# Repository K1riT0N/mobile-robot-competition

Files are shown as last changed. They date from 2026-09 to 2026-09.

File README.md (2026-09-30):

# Mobile Robot Competition

This repository documents a robotics competition project focused on designing and building two mobile robots: one autonomous robot and one manual-controlled robot. The project combines mechanical design, electronics, control programming, testing, and competition documentation into a single development workspace.

The goal is to create competitive robots that can perform assigned field tasks, optimize robot design for reliability, and validate control strategies through repeated testing and iteration.

## Project Overview

The project covers the full engineering cycle for a mobile robot system:

- Mechanical design and CAD modeling
- 3D-printed parts and custom structural components
- Robot assembly and integration
- Sensor, motor, and actuator testing
- Embedded control development and robot programming
- Competition preparation and reporting

The work is divided between:

- Autonomous robot development for self-controlled operation
- Manual robot development for driver-controlled competition tasks
- Testing and tuning for motion, sensing, and field performance

## Repository Structure

- `3D_Printing_Parts_CAD_files/` - CAD files for custom 3D-printed robot parts
- `codes/` - Programming files, testing scripts, and robot control experiments
- `Field_materials_CAD_files/` - Competition field elements and objective models
- `Material_Parts_CAD_files/` - Mechanical and electronic component references
- `Reports/` - Competition-related reports and project documentation
- `Robot_design_CAD_files/` - Full robot assembly and design revisions
- `SuperCool video.mp4` - project video documentation

## Code and Testing

The `codes/` folder contains a mix of control programs and experimental testing work, including:

- Manual control code for robot operation
- Sensor testing folders such as gyro and motor calibration
- Servo and DC motor testing programs
- Development files for iterative competition tuning

This folder reflects the practical process of testing hardware and refining software before final deployment.

## Mechanical Design

The project includes a substantial amount of CAD work for both robot structure and competition field components. These files support:

- Robot frame and mechanism development
- Custom grip, launcher, intake, and support systems
- Part iteration and version tracking
- Full assembly visualization before fabrication

The robot design files show a clear progression from concept to final assembly, with multiple revisions and versions stored in the project.

## Competition Focus

This project is intended to prepare robots for a mobile robotics competition where performance is judged through task completion, reliability, and controlled movement. The system design emphasizes:

- Stability and balance
- Efficient movement and turning
- Sensor-informed control and calibration
- Reusable, modular hardware design
- Continuous refinement based on testing results

## Notes

This GitHub repository is created to organize and share the project work, including design files, software experiments, reports, and competition documentation.

It serves as a record of the team's engineering process and can be used as a reference for future robotics development or similar competition projects.

## Recommended Use

To explore the project:

1. Review the CAD files in the robot and field design folders.
2. Open the testing and code folders to understand the control logic and hardware tuning work.
3. Read the reports in `Reports/` for project milestones and technical documentation.
4. Use the assembly designs as a reference for understanding the final robot configuration.

---

This project demonstrates a complete approach to robot development: from concept to prototype, testing, iteration, and competition-ready design.

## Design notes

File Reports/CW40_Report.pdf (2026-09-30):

## FINAL PROJECT REPORT [WEEK 1]

Group Name: JaiJaiSungLui
Group Number: Group 3
Group members: Nathi, Kullatida, Thannapat Calendar Week: CW40
Date: [Oct 6–12, 2025]

Progress Summary

This week, our team received the components for both the Auto and Manual robots. We began by checking the usability of all electronic components due to the fact that many were found to be broken or damaged. After identifying these issues, we replaced the damaged parts with the working ones.

Next, we made a complete list of all metal parts received, because each part must be returned after the competition. Therefore, we started creating CAD files for every metal part we used in this project including some motor and servo used in this Auto robot.

For the robot design process, we prioritized the Auto Robot over the Manual one. We brainstormed design ideas and built initial prototypes, but we encountered limitations related to the rulebook specification, such as limitation of the robot’s size and the number of motors and servos allowed.

By the end of this week, we came up with the design of the drive frame and the cube collecting mechanism (gate mechanism), and created an assembly CAD file for both the drive frame and gate mechanism.

Next Week Plan

- Begin detailed CAD for the full Auto Robot.
- Start testing motor placement and wiring layout.
- Begin early concept design for the Manual Robot.

Problems Encountered

- Several electronic components were unusable and had to be replaced.
- Design constraints due to limited size and motor count.
- Additional components are required for future design, including wheels, sensors, motors and additional screws.

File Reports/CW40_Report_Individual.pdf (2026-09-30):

### FINAL PROJECT – Individual Report [Week 1]

Group Name: JaiJaiSungLui
Group Number: Group 3
Name: Nathi Ritnatikul
Calendar Week: CW40
Date: [Oct 6–12, 2025]

Week 1 Progress:

- Created CAD files for all metal parts to ensure they are listed for future return.
- Designed several versions of the Auto Robot and refined them according to rulebook specifications.
- Finalized the drive frame and cube collection mechanism (gate) design.
- Created an assembly CAD file of the drive frame and the gate mechanism.

Challenges & Solutions:

- Challenge 1:The rulebook specifications on auto robot have a limitation on its size and the number of electronics components that can be used.
- Solution: We separate the whole robot into each mechanism including drive train, gate mechanism, sensors, and other. Then we assign the electronics to each part so that it is not over the specifications limits.
- Challenge 2: To connect the DC motor and Micro servo to the makeblock metal parts, there is a problem on the size of the screw that the M4 screw (Makeblock) does not fit with the electronics components.
- Solution: Measured and identified compatible screw sizes (either M3 or M2) for proper fit.

Next Week Plan:

- Purchase the required components to complete the robot’s mechanisms.
- Complete the detailed CAD assembly and combine all parts into a single file.
- Begin initial concept design for Manual Robot.

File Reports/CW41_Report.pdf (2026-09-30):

## FINAL PROJECT REPORT [WEEK 2]

Group Name: JaiJaiSungLui
Group Number: Group 3
Group members: Nathi, Kullatida, Thannapat Calendar Week: CW41
Date: [Oct 13–19, 2025]

Progress Summary

This week, our team assembled the drive frame and gate mechanism that were designed in the previous week. Some adjustments are required to ensure the assembled structure fits with the size limitations from the rulebook.

We also began wiring the motors to the Arduino UNO and successfully tested the gyro sensor readings. The CAD design for the Auto Robot (Version 1) was completed and is now ready for real assembling.

For the Manual Robot, we started the design process but faced limitations due to the restricted number of available components that need to be shared to the Auto robot. Therefore, we decided to design it with real components for better visualization and ensure component compatibility.

Next Week Plan

- Begin real assembling the Auto Robot Version 1 and make improvements if necessary.
- Continue wiring and testing the sensors and motor for both Auto and Manual Robots.
- Continue designing the Manual Robot design based on real component setup.

Problems Encountered

- Limited robot size required adjustments to the assembly design.
- Restricted components available for the Manual Robot design.

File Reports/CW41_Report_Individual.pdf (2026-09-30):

### FINAL PROJECT – Individual Report [Week 2]

Group Name: JaiJaiSungLui
Group Number: Group 3
Name: Nathi Ritnatikul
Calendar Week: CW41
Date: [Oct 13–19, 2025]

Week 1 Progress:

- Created CAD files for field objects (Ball and Cube), Electronic parts (Servo and DC motor), and other additional parts.
- Created CAD file for parts that required a 3D printer to be printed and start printing.
- Completed the design on V1 Auto Robot.
- Start designing the Manual robot by separating into different parts according to the functions. (Arms, Drive frame, Launcher)

Challenges & Solutions:

- Challenge 1: While designing the Auto Robot, the rulebook specification on size limit causes the design problem when assembling the cube collecting mechanism to the drive frame.
- Solution: I have made an objective cube in CAD file to compare to the size of the robot and find the most optimal position for the gate mechanism to be placed on.
- Challenge 2: With shared metal parts between the Auto and Manual robots, there is a limit in the number and type of component that can be used which also affects the designing process of the Manual robot.
- Solution: Instead of designing on CAD, we try to assemble with real components left from the Auto robot which visualize how many parts left we got for the Manual robot.

Next Week Plan:

- Finished the Auto robot design and assembled it with real components.
- Test the sensors and motors of the Auto robot.
- Complete the Manual robot design and print the required part for the assembly process.

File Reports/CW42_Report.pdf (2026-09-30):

## FINAL PROJECT REPORT [WEEK 3]

Group Name: JaiJaiSungLui
Group Number: Group 3
Group members: Nathi, Kullatida, Thannapat Calendar Week: CW42
Date: [Oct 20–26, 2025]

Progress Summary

This week, our team is focusing on researching and learning coding strategies for the Auto Robot mission. We studied how to effectively use each electronic component according to its purpose and the mission.

The Auto Robot V1 was finalized and assembled, excluding the wiring process, which we are waiting for adjustment. Moreover, we started 3D printing specific parts required for Auto Robot assembly.

In addition, the Manual Robot design is completed only for the drivetrain and hand mechanism (V1).

Next Week Plan

- Begin wiring and electronic component placement for the Auto Robot,
- Continue testing and coding for the Auto Robot mission.
- Develop and improve the Manual Robot shooting mechanism.

Problems Encountered

- Wiring and electronic component process required properly planned for the most effective result.
- The shooting mechanism for the Manual Robot required a large amount of time to design which takes a lot of time researching on this mechanism.

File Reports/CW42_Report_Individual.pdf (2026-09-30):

### FINAL PROJECT – Individual Report [Week 3]

Group Name: JaiJaiSungLui
Group Number: Group 3
Name: Nathi Ritnatikul
Calendar Week: CW42
Date: [Oct 20–26, 2025]

Week 3 Progress:

- Finalized the Auto Robot V1 and fully assembled the frame excluding the wiring and other electronic components.
- Prepared for wiring and other electronic components adjustment.
- Began designing the Manual Robot by dividing the whole robot into three main parts consisting of drivetrain, hand mechanism, and shooting mechanism.
- Complete First version of the Manual Robot drivetrain and hand mechanism.

Challenges & Solutions:

- Challenge 1: To be able to place all the electronic components, we need to wire them properly for the most effective result.
- Solution: We will design a way to place all the components together without exceeding the size limit and easy for optimization and maintenance.
- Challenge 2: Manual robot is difficult to design due to limited components and require a lot of function for the mission.
- Solution: Split the design into different functions according to the mission for better designing, testing, and adjustment.

Next Week Plan:

- Begin wiring and printing other supports for electronic components for the Auto robot.
- Continue designing and adjusting the Manual robot.
- Testing and optimising both robot structures and coding for better results.

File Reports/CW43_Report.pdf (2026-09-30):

## FINAL PROJECT REPORT [WEEK 4]

Group Name: JaiJaiSungLui
Group Number: Group 3
Group members: Nathi, Kullatida, Thannapat Calendar Week: CW43
Date: [Oct 27 – Nov 2, 2025]

Progress Summary

This week, the Auto Robot was completed and now in the code testing and improvement phase. So, this week we will focus on the Manual Robot, specifically the launcher mechanism, which is really challenging. The first design used a TT motor to launch the ball and successfully launched the 70mm diameter ball about 450mm, but was unable to launch the 100mm diameter ball.

After multiple adjustments to the arm length and angle of freedom. We are still unable to launch a big ball. Therefore, we decided to focus on launching small balls since there are more small balls than larger ones. The current Manual Robot Version 2 is completed, which still requires optimization on the throwing arm.

Next, our team plans to replace the aluminum launcher arm with a fully 3D printed arm instead for lighter weight and to improve the performance. Both robots are expected to be finalized and tested on the field next week.

Next Week Plan

- Complete both Auto and Manual Robots and test them on the field.
- Replace aluminum launcher arm with 3D printed version.
- Optimize throwing performance and adjust strategy based on testing results.

Problems Encountered

- The TT motor generated not enough torque for the launcher to launch the larger balls.
- Arm adjustment and angle tuning did not improve the range.
- Strategy had to be adapted if the robot was unable to launch a larger ball.

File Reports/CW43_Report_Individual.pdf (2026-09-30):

### FINAL PROJECT – Individual Report [Week 4]

Group Name: JaiJaiSungLui
Group Number: Group 3
Name: Nathi Ritnatikul
Calendar Week: CW43
Date: [Oct 27 – Nov 2, 2025]

Week 4 Progress:

- Designed and developed 3D CAD models for the Manual Robot launcher arm to prepare for 3D printing and testing.
- Test and improve the Auto Robot coding and performance.
- Redesign the launcher mechanism and improve the results.

Challenges & Solutions:

- Challenge 1: The TT motor did not generate enough torque to throw large balls
- Solution: Redesign the arm to minimize the weight of the arm as much as possible to be able to launch it.
- Challenge 2: When driving the Manual Robot, it sometimes falls to the back.
- Solution: We add a support at the back to prevent the robot from falling.

Next Week Plan:

- 3D print and install the redesigned launcher arm.
- Testing both robots on the field.
- Finalize the CAD design based on real test results.

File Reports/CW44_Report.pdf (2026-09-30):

## FINAL PROJECT REPORT [FINAL WEEK]

Group Name: JaiJaiSungLui
Group Number: Group 3
Group members: Nathi, Kullatida, Thannapat Calendar Week: CW44
Date: [Nov 3– 9, 2025]

Progress Summary

This week, we focused on improving the Manual Robot shooting mechanism. The previous design implemented a catapult-based launcher mechanism which is not working for large balls. Therefore, we changed the mechanism into a striking mechanism. This new mechanism allows us to be able to intake a ball and strike it. This new design provided more effectiveness and consistency in launching big balls.

Both Manual Robot and Auto Robot were now finalized with nothing changed from the auto robot. However, we have optimized the Manual Robot gripper mechanism, where we make the gripper arm parallel to the ground so that it can grip the balls more firmly than before. We added an intake rail for the ball to be able to slide to the launcher and prepare to be launched.

For the coding part, the Manual Robot code is finished, but the Auto Robot code is still not working. When run separated, it was able to run effectively. However, when all code is combined, the robot does not actually run, and debugging is ongoing.

Problems Encountered

- When designing the striking mechanism the mass of the arm is too heavy for the motor to be able to turn. Therefore, we 3D printed the whole arm to be lightweight.
- The auto robot code is still having an issue, the debugging is still ongoing.

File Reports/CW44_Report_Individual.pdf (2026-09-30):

### FINAL PROJECT – Individual Report [Final Week]

Group Name: JaiJaiSungLui
Group Number: Group 3
Name: Nathi Ritnatikul
Calendar Week: CW44
Date: [Nov 3–9, 2025]

Week 5 Progress:

- Finalized both auto robot and manual robot with optimized design adjustments
- Coded the manual robot control system, allowing the robot to be able to be controlled using a controller.

Challenges & Solutions:

- Challenge 1: The design of the striker arm is too heavy using aluminum parts
- Solution: CAD a 3D part so that we can adjust the weight of the arm and its design.
- Challenge 2: When intaking the ball, it sometimes falls to the ground instead of getting into the launcher.
- Solution: Making an intake rail for the ball to be able to slide into the launcher properly.

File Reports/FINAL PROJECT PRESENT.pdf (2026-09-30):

## FINAL PROJECT PRESENTATION

AUTONOMUS ROBOT COMPONENTS
CONTROLLER [Arduino UNO]
- reliable
- have 14 digital I/O pins, able to connect to many sensors, motor and servo

[Motor Driver]
- have two channels that are perfect for two driving motor
- able to control the speed of each motor for stability

DRIVING [TT Gear DC Motor]
- lgihtweight
- enough torque to run smoothly
-need motor driver and battery supply to be able to run

COLLECTOR [SG90 micro servo]
- lightweight with only 9 g
- with enough torque of two servo that be able to push a 70mm cube

GYRO SENSOR [MPU6050]
- it's a combination of gyroscope and the accelerometer
- when uses with motor driver, we can control the speed of each motor to stable the driving

ULTRASONIC [HC-SR04]
- have a range of 20mm to 4000mm
- have resolution of about 3mm

MANUAL ROBOT COMPONENTS
CONTROLLER [mBot2 + CyberPi]
- it support WiFi and Bluetooth 5.0

- able to control it with makeblock controller

DRIVING [Encoder Motor]
- it can rotate 360 degrees
- torque of 0.8 kg cm
- be able to control the power and speed

GRIPPER [MS-1.5A Servo]
- rotates 180 degrees
- torque of 1.8 kg cm that be able to grab different size balls

LIFTER [Digital Servo]
- has a really high torque, over 20 kg cm
- be able to handle the arm, two small servo, and the ball all together

STRIKER [TT Gear DC Motor]
- has a speed of 200 RPM that generate torque of about 0.8 kg cm
- this motor generate speed enough to strike a ball to a prefreable range.

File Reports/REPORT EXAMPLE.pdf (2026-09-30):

## RAI Robotics Competition Report

Semester1 Final Project

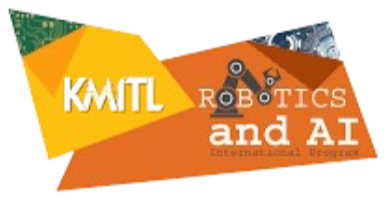
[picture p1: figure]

## Submit to Dr. Poom Konghuayrob

## Report By:

## Hsu Myat Noe , Sec1

## Moe Chan Myae Maung ,Sec2

## Poonnachote Kaewsuwan , Sec3

# Auto Robot

# Part List

2x Yellow DC Motor | 3x Ultra-distance sensors
1x Arduino UNO | 1 x L298N Motor Drive Module

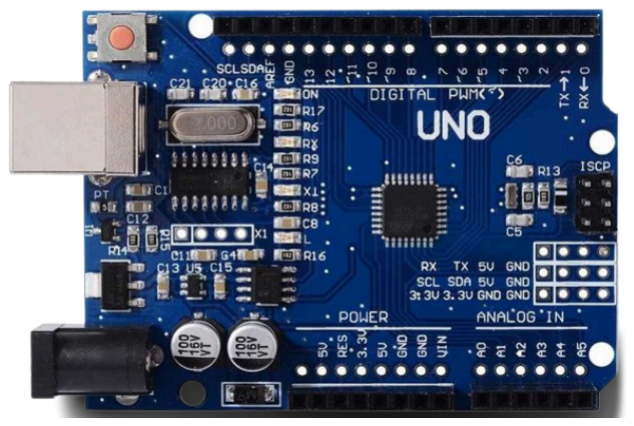
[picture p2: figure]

1x battery 7.4V

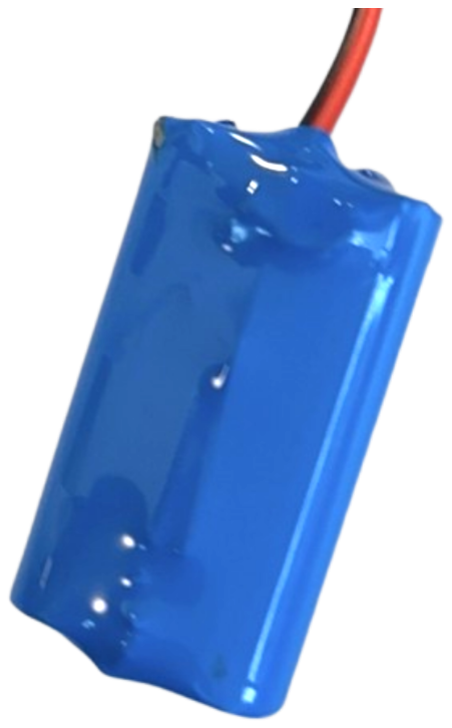
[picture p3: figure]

# Assembly

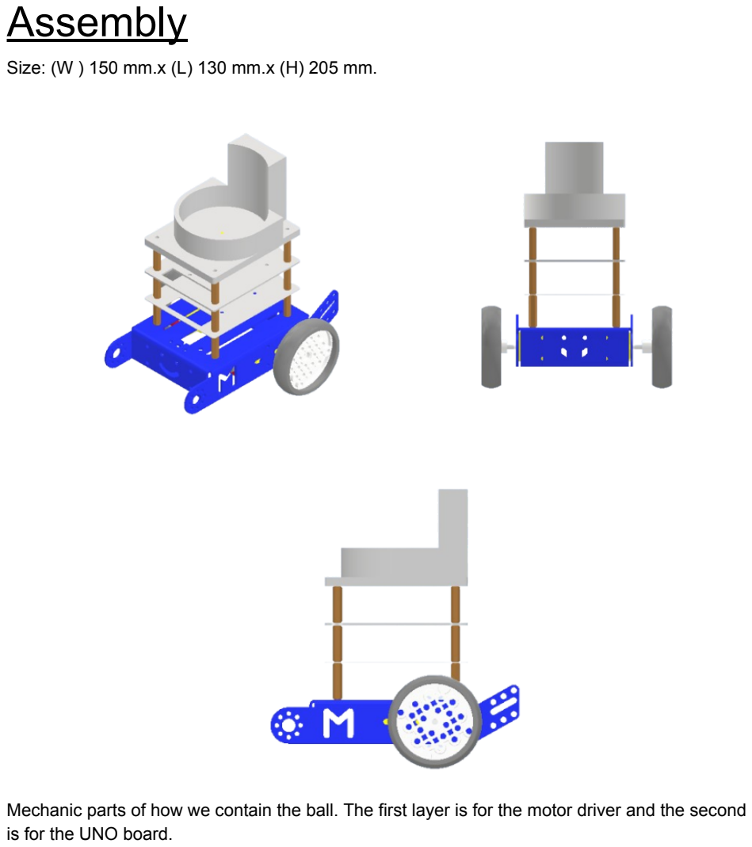
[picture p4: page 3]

Size: (W ) 150 mm.x (L) 130 mm.x (H) 205 mm.

Mechanic parts of how we contain the ball. The first layer is for the motor driver and the second is for the UNO board.

# Robot Photo

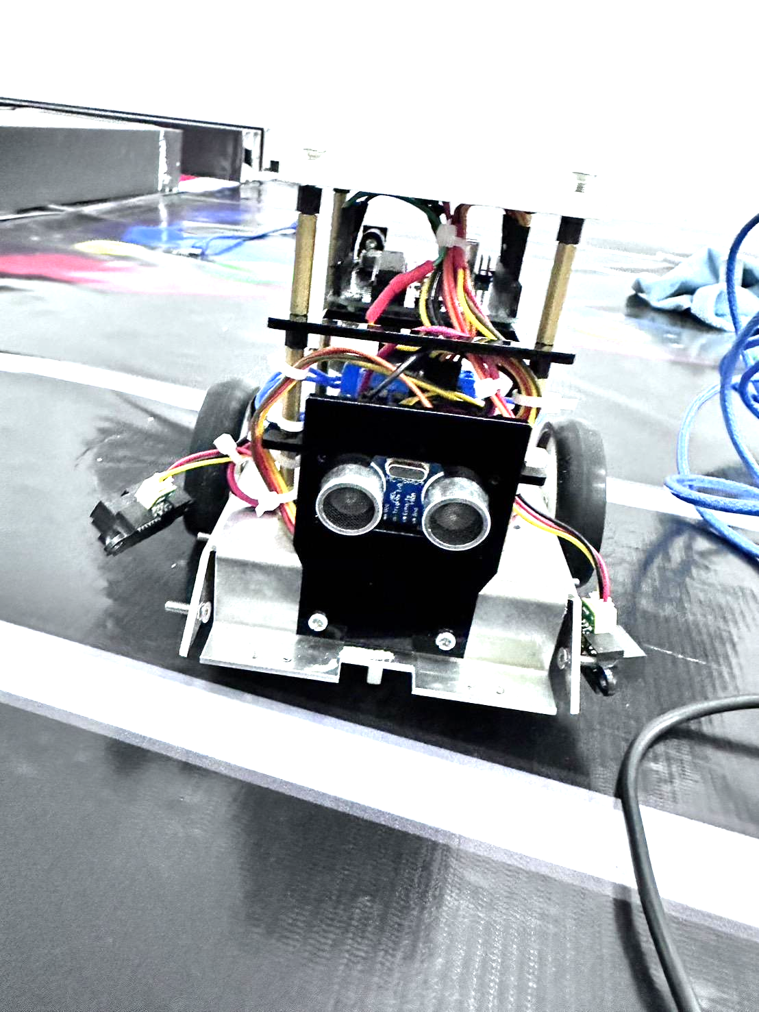
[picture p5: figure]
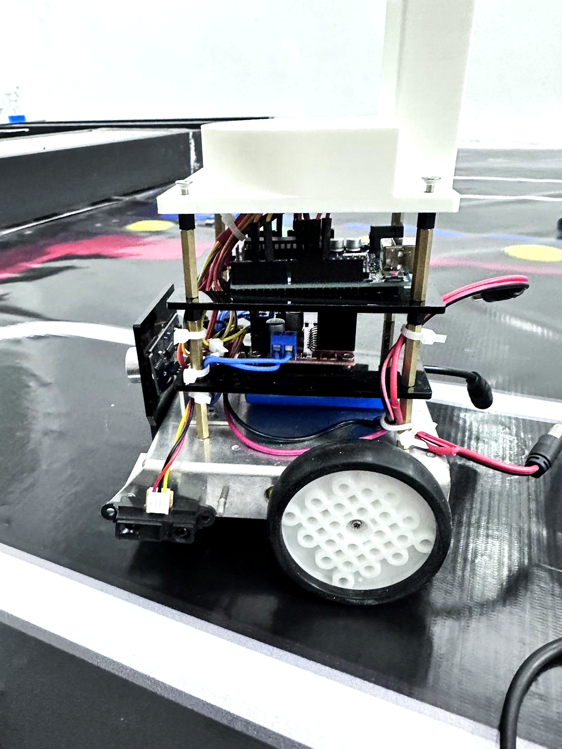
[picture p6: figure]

# Electrical Diagram

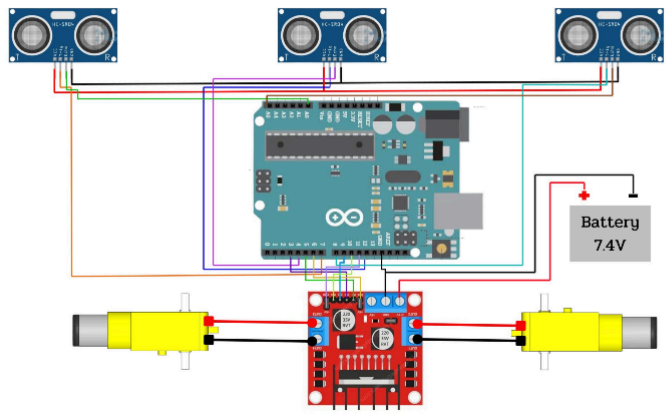
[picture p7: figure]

# Robot Video

SuperCoolVideo.mp4 (https://drive.google.com/file/d/1fwqNrXh0kFcKUcSBRT9qSalyOQuXsnVy/view?usp=sharing)

# Flow Chart

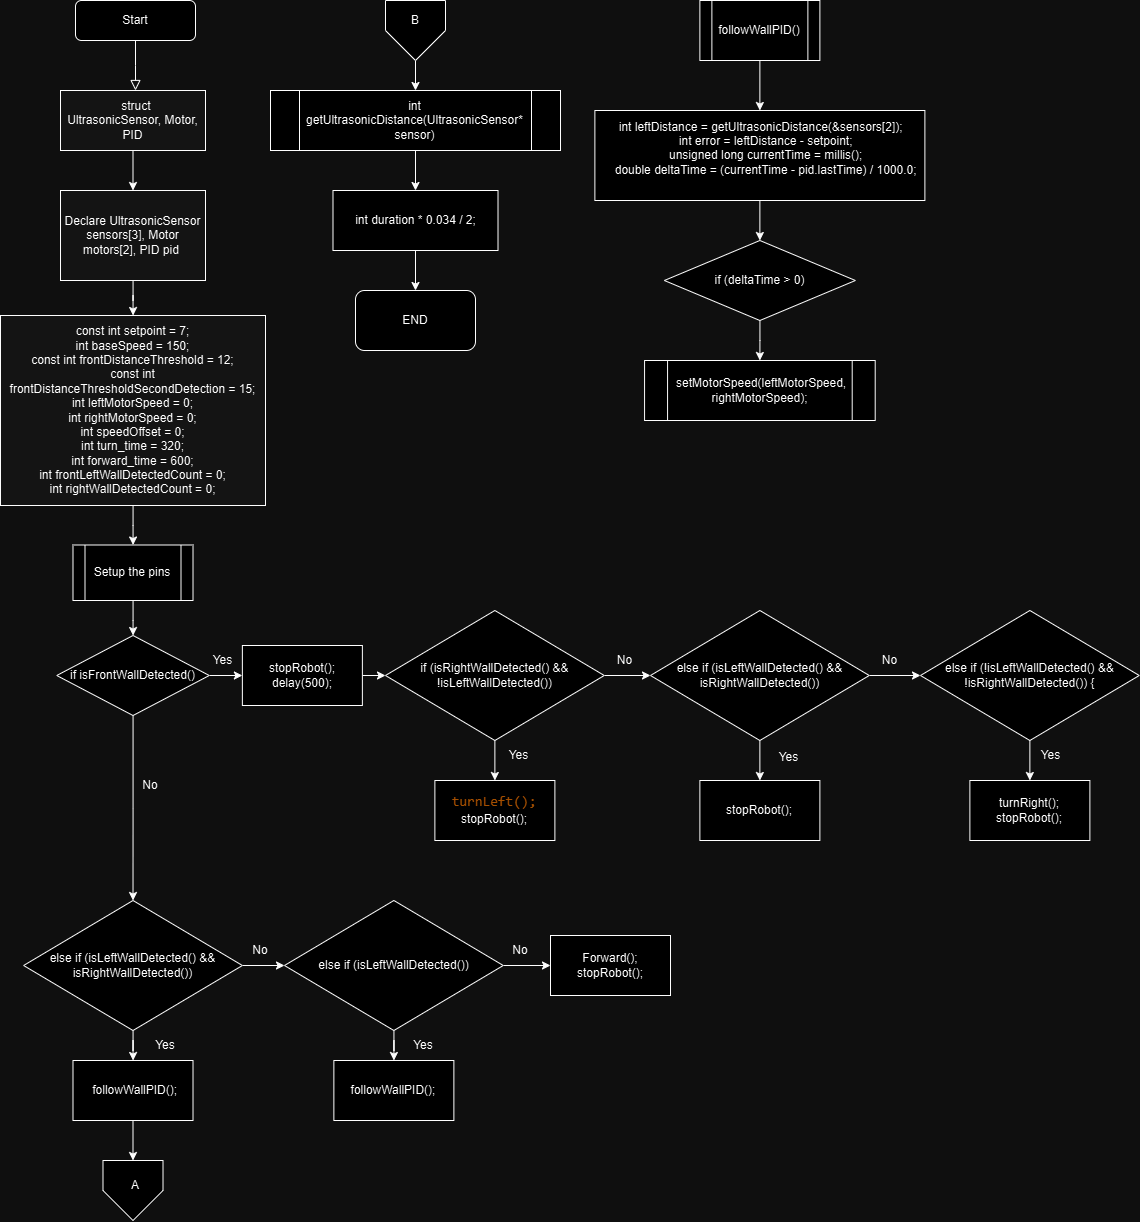
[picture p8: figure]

# Coding and explanation

struct UltrasonicSensor {
int trigPin;
int echoPin;
};

struct Motor {
int forwardPin;
int backwardPin;
int speedPin;
};

const double Kp = 8.0, Ki = 0.00001, Kd = 5.0;
const int setpoint = 7, baseSpeed = 125, turn_time = 320, forward_time = 600;

UltrasonicSensor sensors[] = {
{8, A5}, // Right
{12, 4}, // Front
{7, A0} // Left
};

Motor motors[] = {
{5, 3, 6}, // Motor 1
{9, 10, 11} // Motor 2
};

double prevError = 0, integral = 0;
unsigned long lastTime = 0;
int speedOffset = 0, leftMotorSpeed = 0, rightMotorSpeed = 0;

void setup() {
Serial.begin(9600);
Serial.println(F("Initialize System"));

for (UltrasonicSensor &sensor : sensors) { pinMode(sensor.trigPin, OUTPUT); pinMode(sensor.echoPin, INPUT);
}
for (Motor &motor : motors) { pinMode(motor.forwardPin, OUTPUT); pinMode(motor.backwardPin, OUTPUT); pinMode(motor.speedPin, OUTPUT);

}
}

void loop() {
if (isWallDetected(sensors[1], 9)) {
stopRobot();
delay(500);
if (isWallDetected(sensors[2], 18) && !isWallDetected(sensors[0], 18)) { Serial.println("Front and Left wall detected ---------- Turn Right!!!"); turnRight();
delay(350);
} else if (isWallDetected(sensors[0], 18) && !isWallDetected(sensors[2], 18)) { Serial.println("Front and Right wall detected ---------- Turn Left!!!"); turnLeft();
delay(turn_time);
} else if (isWallDetected(sensors[2], 18) && isWallDetected(sensors[0], 18)) { Serial.println("All walls detected --- Stop");
stopRobot();
} else {
Serial.println("Front only detected, Turn Right"); turnRight();
delay(turn_time);
}
stopRobot();
delay(500);
} else if (isWallDetected(sensors[2], 18) && isWallDetected(sensors[0], 18)) { Serial.println("Left and Right walls detected, following left wall"); followWallPID();
} else if (isWallDetected(sensors[2], 18)) {
Serial.println("Left wall detected, turning right");
turnRight();
delay(turn_time);
stopRobot();
delay(500);
} else if (isWallDetected(sensors[0], 18)) {
Serial.println("Right wall detected, moving forward and turning left"); moveForward();
delay(forward_time);
stopRobot();
turnLeft();
delay(turn_time);
stopRobot();
delay(500);
} else {

Serial.println("No walls detected, moving forward"); moveForward();
delay(forward_time);
stopRobot();
delay(500);
}
}

int getDistance(UltrasonicSensor *sensor) { digitalWrite(sensor->trigPin, LOW); delayMicroseconds(2);
digitalWrite(sensor->trigPin, HIGH); delayMicroseconds(10);
digitalWrite(sensor->trigPin, LOW);

int duration = pulseIn(sensor->echoPin, HIGH);
return duration * 0.034 / 2;
}

bool isWallDetected(UltrasonicSensor sensor, int threshold) { return getDistance(&sensor) < threshold;
}

void followWallPID() {
int leftDistance = getDistance(&sensors[2]);
int error = leftDistance - setpoint;

unsigned long currentTime = millis();
double deltaTime = (currentTime - lastTime) / 1000.0;

if (deltaTime > 0) {
integral += error * deltaTime;
double derivative = (error - prevError) / deltaTime;
double controlSignal = Kp * error + Ki * integral + Kd * derivative; prevError = error;
lastTime = currentTime;

speedOffset = constrain(controlSignal, -100, 100); leftMotorSpeed = baseSpeed - speedOffset; rightMotorSpeed = baseSpeed + speedOffset;

setMotorSpeed(leftMotorSpeed, rightMotorSpeed); }
}

void setMotorSpeed(int leftSpeed, int rightSpeed) { digitalWrite(motors[0].forwardPin, HIGH); digitalWrite(motors[1].forwardPin, HIGH); digitalWrite(motors[0].backwardPin, LOW); digitalWrite(motors[1].backwardPin, LOW); analogWrite(motors[0].speedPin, rightSpeed); analogWrite(motors[1].speedPin, leftSpeed); }

void stopRobot() {
for (Motor &motor : motors) { digitalWrite(motor.forwardPin, LOW); digitalWrite(motor.backwardPin, LOW); analogWrite(motor.speedPin, 0);
}
}

void moveForward() {
setMotorSpeed(200, 200);
}

void turnLeft() {
digitalWrite(motors[0].forwardPin, HIGH); digitalWrite(motors[1].forwardPin, LOW); digitalWrite(motors[0].backwardPin, LOW); digitalWrite(motors[1].backwardPin, HIGH); analogWrite(motors[0].speedPin, 200); analogWrite(motors[1].speedPin, 200);
}

void turnRight() {
digitalWrite(motors[0].forwardPin, LOW); digitalWrite(motors[1].forwardPin, HIGH); digitalWrite(motors[0].backwardPin, HIGH); digitalWrite(motors[1].backwardPin, LOW); analogWrite(motors[0].speedPin, 200); analogWrite(motors[1].speedPin, 200);
}

## Code Explanation

This code is for a robot that uses ultrasonic sensors and a Proportional-Integral-Derivative (PID) control system to navigate and avoid obstacles. The robot is equipped with sensors to detect walls on its left, right, and front sides, and it has motors controlled by a PID loop to adjust its path. Here's a breakdown of the main components and logic:

1. Sensor and Motor Pin Setup: The code defines pins for three ultrasonic sensors (left, right, and front) and for motor control. It sets the motor pin modes to control the robot’s movement, including moving forward, turning left or right, and stopping.

### 2. PID Control Constants: The code defines constants (Kp, Ki, and Kd) for the PID

controller, which are adjusted to keep the robot at a target distance (setpoint) from the wall. Kp is the proportional gain, which directly affects how aggressively the robot adjusts its direction to maintain a distance from the wall. Ki is the integral gain, a small value to account for minor adjustments, and Kd is the derivative gain, which smooths corrections to avoid oscillation.

### 3. Wall Detection Functions: Each ultrasonic sensor has a function

(isFrontWallDetected, isLeftWallDetected, and isRightWallDetected) that
calculates the distance to a wall. These functions return a Boolean value, indicating if the wall is within a predefined range, allowing the robot to detect obstacles on each side.

### 4. Wall Following Logic: Inside the loop() function, the robot checks each sensor's

readings. Based on the presence of walls, the robot decides how to move:
- If a wall is detected in front, the robot stops and chooses to turn left or right based on the readings from the side sensors.
- If only a left or right wall is detected, the robot turns accordingly.
- If no walls are detected, the robot moves forward.
- If both side walls are detected, it activates followWallPID() to maintain a set distance from the left wall.

### 5. PID-Based Wall Following: The followWallPID() function calculates the error

between the current distance to the left wall and the setpoint. Using this error, the function calculates the control signal based on the PID formula, adjusting the robot's motor speeds (leftMotorSpeed and rightMotorSpeed) to stay close to the wall. The PID controller ensures smoother and more stable adjustments, particularly in environments where maintaining a fixed distance from walls is essential.

### 6. Robot Movements: Helper functions (stopRobot, Forward, turnLeft, and

turnRight) control specific movements. They set the motor directions and speed values to execute each movement, ensuring the robot can respond to obstacles effectively.

### 7. Timing Adjustments: Delays in each function (like delay(turn_time)) ensure the

robot has time to complete turns or stops as it navigates through different scenarios.

The PID controller helps the robot maintain an optimal distance from obstacles and navigate effectively. This combination of sensors, control logic, and PID adjustments allows the robot to operate autonomously, respond to its surroundings, and avoid collisions.

# Manual Robot

# Part List

2x MS - 1.5A Servos | 1x MG996R Servo | 1x 180 Optical Encoder Motor
1x CyberPi | 1x Mbot2 mbot neo shield | 2x Yellow DC motors

1x battery 7.4V

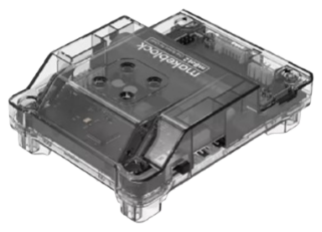
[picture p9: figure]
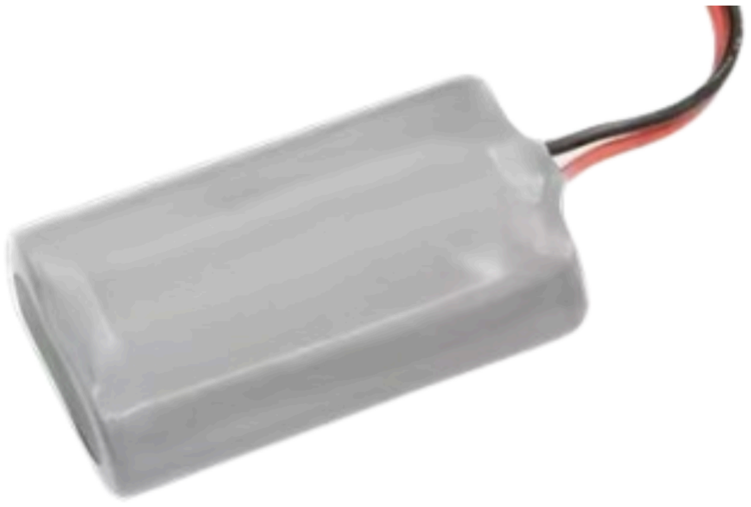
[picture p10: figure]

# Assembly

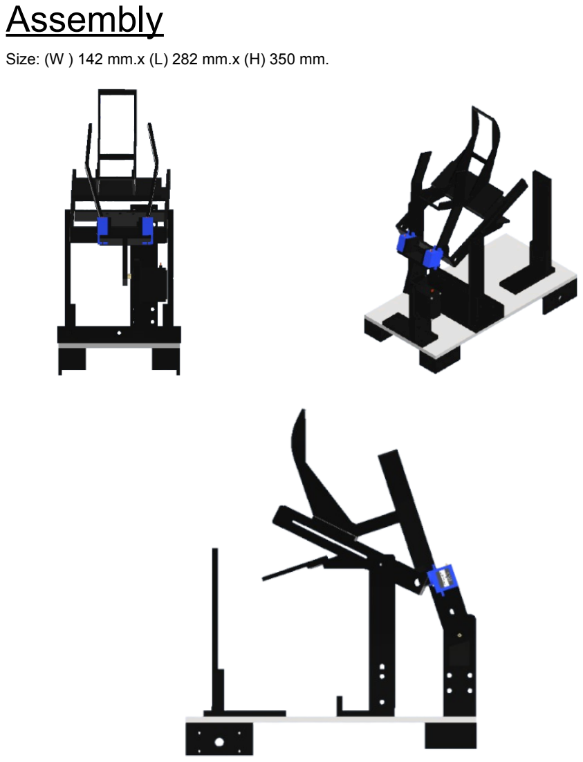
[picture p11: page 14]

Size: (W ) 142 mm.x (L) 282 mm.x (H) 350 mm.

# Robot Photo

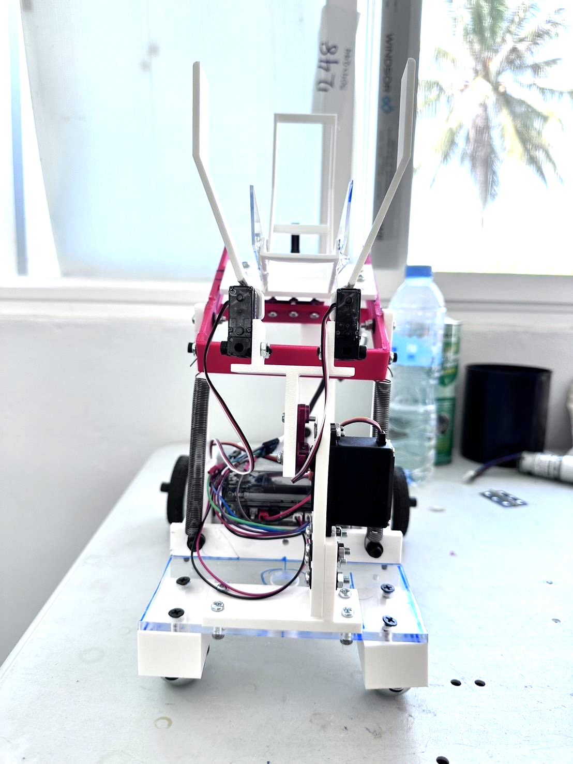
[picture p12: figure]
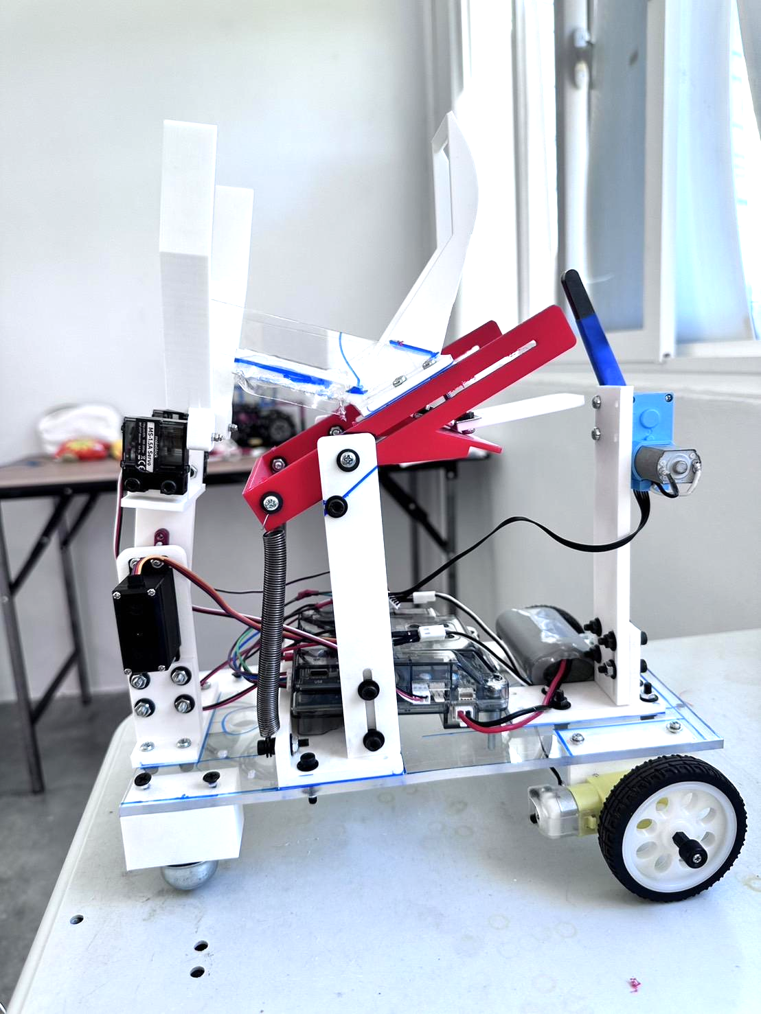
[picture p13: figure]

# Electrical Diagram

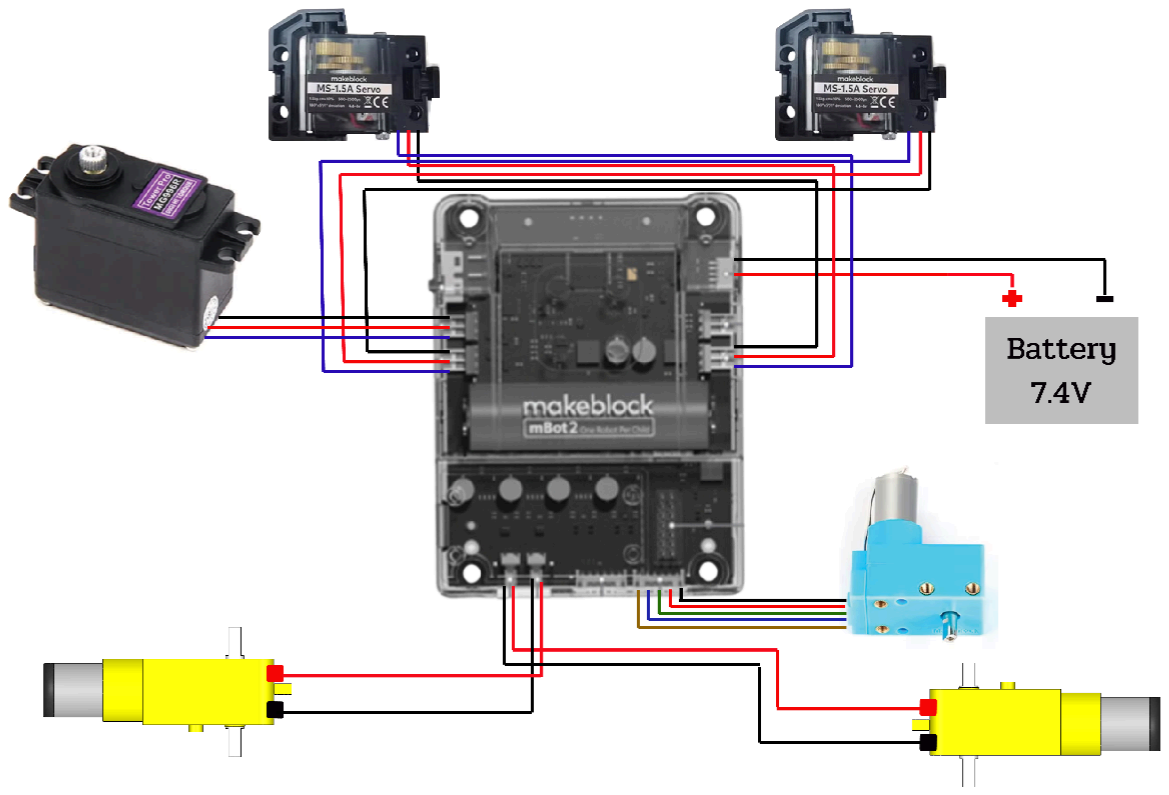
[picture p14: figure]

# Flow Chart

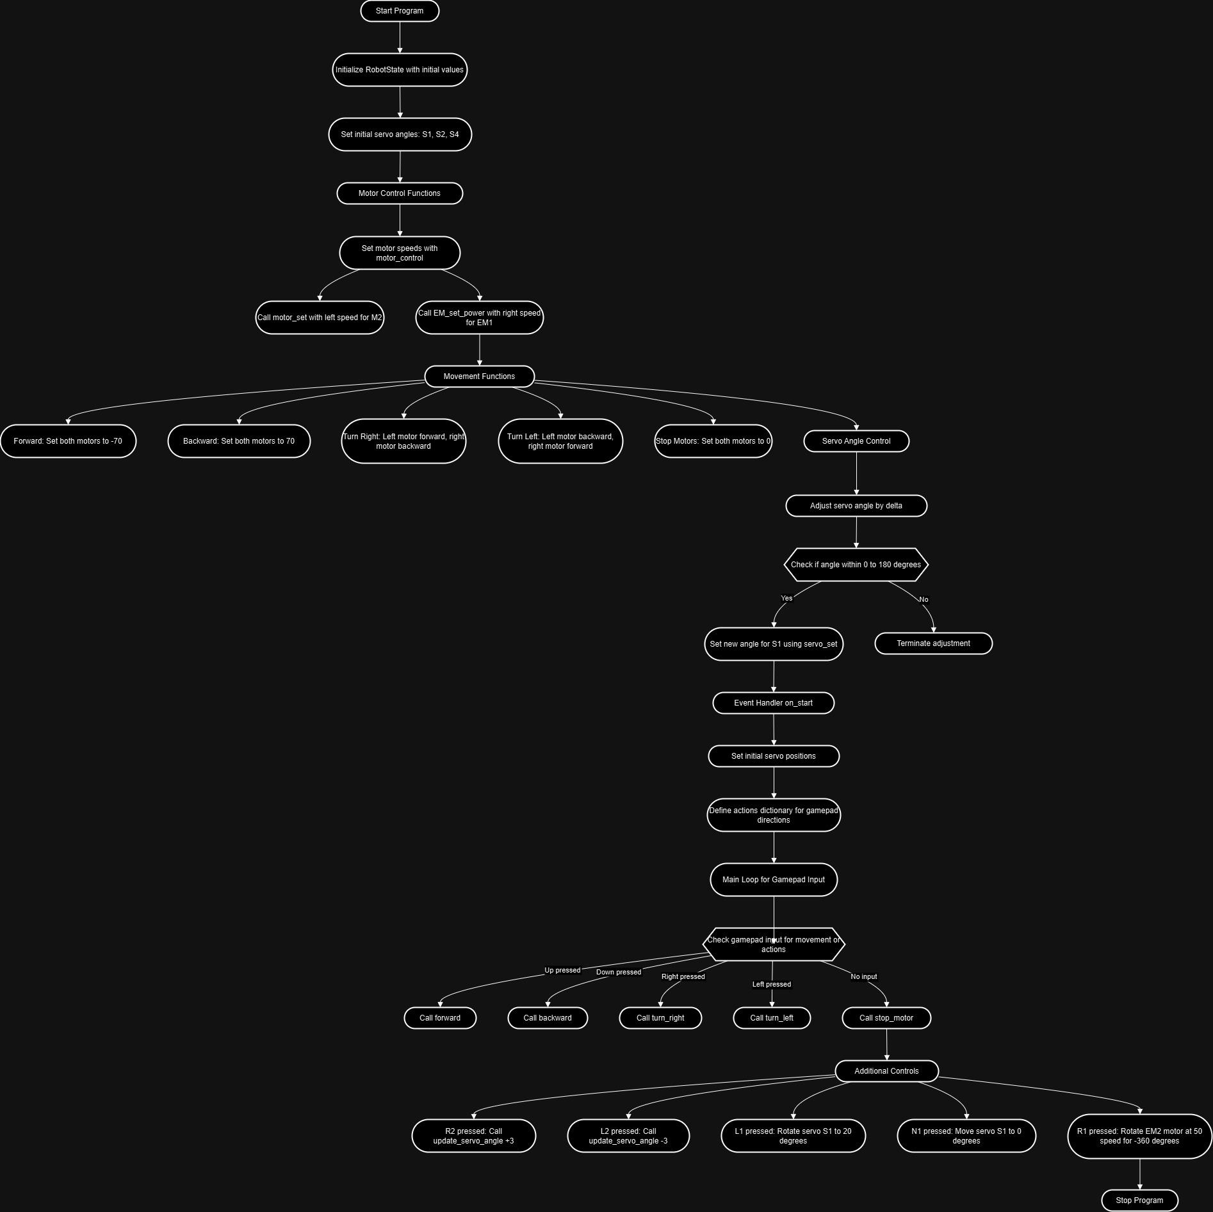
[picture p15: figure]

# Code and explanation

import mbot2, event, time, cyberpi, gamepad

class RobotState:
def __init__(self):
self.servo_angle = 130
self.motor_speeds = {'M2': 0, 'EM1': 0} self.servo_angles = {'S1': 130, 'S2': 0, 'S4': 90}

robot_state = RobotState()

def motor_control(left_speed, right_speed): mbot2.motor_set(left_speed, "M2") mbot2.EM_set_power(right_speed, "EM1")

def forward():
motor_control(-70, -70)

def backward():
motor_control(70, 70)

def turn_right():
motor_control(70, -70)

def turn_left():
motor_control(-70, 70)

def stop_motor():
motor_control(0, 0)

def update_servo_angle(delta):
if 0 <= robot_state.servo_angle + delta <= 180: robot_state.servo_angle += delta mbot2.servo_set(robot_state.servo_angle, "S1") time.sleep(0.02)

@event.start

def on_start():
mbot2.servo_set(robot_state.servo_angles["S1"], "S1") mbot2.servo_set(robot_state.servo_angles["S4"], "S4") mbot2.servo_set(robot_state.servo_angles["S2"], "S2")

actions = {
'Up': forward,
'Down': backward,
'Right': turn_right,
'Left': turn_left
}

while True:
moving = False

for key, action in actions.items(): if gamepad.is_key_pressed(key): action()
moving = True

if not moving:
stop_motor()

if gamepad.is_key_pressed('R2'): update_servo_angle(3)

elif gamepad.is_key_pressed('L2'): update_servo_angle(-3)

if gamepad.is_key_pressed('L1'): mbot2.servo_drive(mbot2.servo_get("S1"), 20, 0, 70) if gamepad.is_key_pressed('N1'): mbot2.servo_drive(mbot2.servo_get("S1"), 0, 0, 90) if gamepad.is_key_pressed('R1'):

mbot2.EM_turn(-360, 50, "EM2")

1. Class RobotState
This class specifies a fundamental framework for storing the robot's current state, including motor speeds and servo angles.
The initial value of servo_angle is 130 degrees.
motor_speeds Motor speed values are stored in a dictionary for ports "M2" and "EM1." The initial angles for servos labeled "S1," "S2," and "S4" are stored in the servo_angles dictionary.
2. Functions of Motor Control
By adjusting motor speeds, these functions control the robot's motion.
The left and right motors' speeds are set by motor_control(left_speed, right_speed). (left_speed, "M2") mbot2.motor_set regulates the motor on "M2."
(right_speed, "EM1") mbot2.EM_set_power regulates the motor on "EM1." Functions of Movement:
forward(): Sets both motors to -70 (probably in reverse) to move the robot forward. reverse(): Uses both motors to move the robot backward at +70.
turn_right(): For a right turn, it sets the left motor forward and the right motor backward. turn_left(): For a left turn, it sets the right motor forward and the left motor backward. stop_motor(): Sets speeds to 0 to halt both motors.
3. Servo Angle Control
update_servo_angle(delta): Modifies the servo "S1"'s angle by delta, which can be either +3 or -3 degrees.
updates the servo angle after making sure the angle remains between 0 and 180°.
4. The on_start event handler
Initialisation: This function sets the servos to their initial angles specified in robot_state at the beginning of the program.
Dictionary of actions: translates the Up, Down, Right, and Left gamepad directions into movement functions.
Main Loop: Constantly monitors gamepad inputs to regulate the robot's actions:
When a directional button (Up, Down, Right, or Left) is pressed, the robot moves in the appropriate direction.

The robot is stopped by stop_motor() if no movement button is pushed. Update_servo_angle() is called by the R2 and L2 buttons to regulate servo angle modifications.
Extra Controls for the Gamepad:
Servo "S1" is rotated by L1 to 20 degrees.
Servo "S1" is moved to 0 degrees by N1.
R1: Starts the motor on "EM2" to rotate at 50 rpm for a complete -360° revolution.

# How does our shooter work?

Our shooter mechanism primarily uses springs to launch the ball, with two springs working together to generate a stronger force for returning to the original position. To amplify this force, we’ve incorporated an encoder motor that pushes the shooter in the opposite direction of the spring tension, building up even more resistive force. This setup allows the motor to compress the springs further, creating a higher potential energy that’s released when the motor stops pushing. The encoder motor also enables precise control over the loading phase, making sure we reach the ideal force consistently.

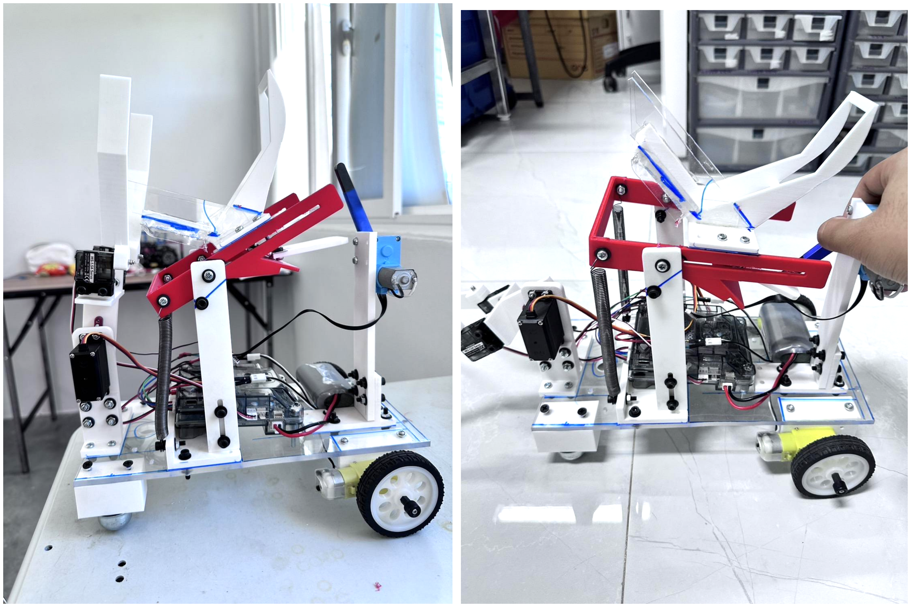
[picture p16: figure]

Before Extend | After Extend

# Projectile

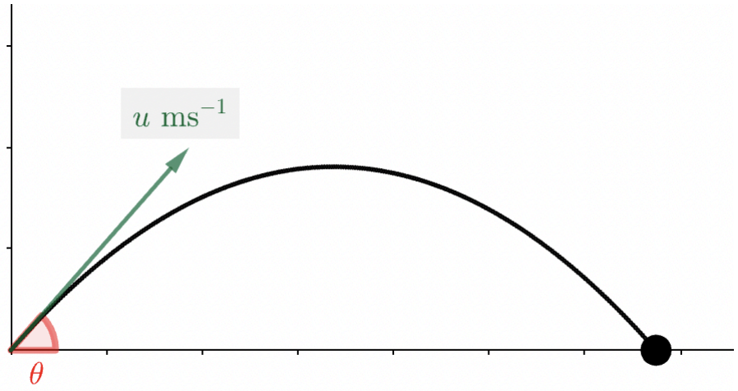
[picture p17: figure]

Potential Energy in the Spring (PE_spring): PEspring =

1
2

kx

2

As the spring releases, the potential energy becomes kinetic energy: KE =

1
2 mv

2

Since energy is conserved,

1
2

kx

2 =
1
2 mv

2

Solving for Velocity: v =

kx

2

m
Horizontal Velocity = v cos(θ) Vertical Velocity = v sin(θ)

Time of Flight(T) = T =

2v sin(θ)
g
Range (R) = R = v cos(θ) × | ←Horizontal Range

2v sin(θ)
g

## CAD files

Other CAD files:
Robot_design_CAD_files/OldVersions/Full_Manual_Robot_V1.0002.dwg
Robot_design_CAD_files/OldVersions/Full_Auto_Robot.0001.dwg
Robot_design_CAD_files/OldVersions/Cube_collecting_mechanism.0001.dwg
3D_Printing_Parts_CAD_files/ArduinoUnoCaseLowerPartNoShield.ipt
3D_Printing_Parts_CAD_files/ArduinoUnoCaseLowerPartRelayShield.ipt
3D_Printing_Parts_CAD_files/Launcher_Arm_V1.ipt
3D_Printing_Parts_CAD_files/Launcher_Arm_V2.ipt
3D_Printing_Parts_CAD_files/Launcher_hand.ipt
3D_Printing_Parts_CAD_files/Launcher_shaft.ipt
3D_Printing_Parts_CAD_files/Launcher_support.ipt
3D_Printing_Parts_CAD_files/Micro_Servo_Cap.ipt
3D_Printing_Parts_CAD_files/Micro_servo_frame_1.ipt
3D_Printing_Parts_CAD_files/Micro_servo_frame_2.ipt
3D_Printing_Parts_CAD_files/OldVersions/Launcher_Arm_V1.0003.ipt
3D_Printing_Parts_CAD_files/OldVersions/Launcher_hand.0001.ipt
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

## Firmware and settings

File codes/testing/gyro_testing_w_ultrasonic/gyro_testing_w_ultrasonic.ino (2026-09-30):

#include <Wire.h>
#include <MPU6050_tockn.h>
#include <Servo.h>

MPU6050 mpu(Wire);

// --- Motor Pins ---
#define MOTOR_B_EN 5
#define MOTOR_B_1 6
#define MOTOR_B_2 7

#define MOTOR_A_EN 10
#define MOTOR_A_1 9
#define MOTOR_A_2 8

// --- Ultrasonic Pins ---
#define TRIG 11
#define ECHO 12

// --- Servo Pins ---
Servo myservo1;  // เก็บของ
Servo myservo2;  // ปล่อยของ

// --- Gyro Variables ---
float baseYaw = 0;
float kp = 3.0;     // ปรับค่าให้ตรงของจริง
int baseSpeed = 160;

// --- Timing Variables ---
unsigned long prevTime = 0;
const unsigned long interval = 50; // อัปเดตทุก 50 ms (20 Hz)

// --- Mission Variables ---
int task = 0;   // ภารกิจ
float startDist = 0; // ระยะเริ่มต้น
float currentDist = 0;

// ------------------------------------------------------------
// Ultrasonic Function
// ------------------------------------------------------------
float readDistance() {
  digitalWrite(TRIG, LOW);
  delayMicroseconds(2);
  digitalWrite(TRIG, HIGH);
  delayMicroseconds(10);
  digitalWrite(TRIG, LOW);
  long duration = pulseIn(ECHO, HIGH);
  return duration * 0.034 / 2.0; // หน่วย cm
}

// ------------------------------------------------------------
// Motor Control
// ------------------------------------------------------------
void drive(int leftSpeed, int rightSpeed) {
  leftSpeed = constrain(leftSpeed, -255, 255);
  rightSpeed = constrain(rightSpeed, -255, 255);

  // Motor A (ขวา)
  if (rightSpeed >= 0) {
    digitalWrite(MOTOR_A_1, LOW);
    digitalWrite(MOTOR_A_2, HIGH);
  } else {
    digitalWrite(MOTOR_A_1, HIGH);
    digitalWrite(MOTOR_A_2, LOW);
  }
  analogWrite(MOTOR_A_EN, abs(rightSpeed));

  // Motor B (ซ้าย)
  if (leftSpeed >= 0) {
    digitalWrite(MOTOR_B_1, HIGH);
    digitalWrite(MOTOR_B_2, LOW);
  } else {
    digitalWrite(MOTOR_B_1, LOW);
    digitalWrite(MOTOR_B_2, HIGH);
  }
  analogWrite(MOTOR_B_EN, abs(leftSpeed));
}

void stopMotors() {
  analogWrite(MOTOR_A_EN, 0);
  analogWrite(MOTOR_B_EN, 0);
}

// ------------------------------------------------------------
// Gyro Straight Drive
// ------------------------------------------------------------
void goStraight(float targetYaw) {
  mpu.update();
  float currentYaw = mpu.getAngleZ();
  float error = currentYaw - targetYaw;
  float correction = kp * error;

  int leftSpeed = baseSpeed - correction;
  int rightSpeed = baseSpeed + correction;
  drive(leftSpeed, rightSpeed);

  Serial.print("Yaw: "); Serial.print(currentYaw);
  Serial.print(" | Error: "); Serial.print(error);
  Serial.print(" | Left: "); Serial.print(leftSpeed);
  Serial.print(" | Right: "); Serial.println(rightSpeed);
}

// ------------------------------------------------------------
// Servo Control
// ------------------------------------------------------------
void pickup() {
  myservo1.write(90); delay(800);
  myservo1.write(0);
}

void release() {
  myservo2.write(90); delay(800);
  myservo2.write(0);
}

// ------------------------------------------------------------
// Setup
// ------------------------------------------------------------
void setup() {
  Serial.begin(115200);
  Wire.begin();
  mpu.begin();
  mpu.calcGyroOffsets(true);
  Serial.println("Gyro calibrated.");

  pinMode(MOTOR_A_1, OUTPUT);
  pinMode(MOTOR_A_2, OUTPUT);
  pinMode(MOTOR_A_EN, OUTPUT);
  pinMode(MOTOR_B_1, OUTPUT);
  pinMode(MOTOR_B_2, OUTPUT);
  pinMode(MOTOR_B_EN, OUTPUT);

  pinMode(TRIG, OUTPUT);
  pinMode(ECHO, INPUT);

  myservo1.attach(2);
  myservo2.attach(3);
  myservo1.write(0);
  myservo2.write(0);

  delay(1000);
  mpu.update();
  baseYaw = mpu.getAngleZ();

  // อ่านระยะเริ่มต้นจาก ultrasonic
  startDist = readDistance();
  Serial.print("Start distance: "); Serial.println(startDist);
}

// ------------------------------------------------------------
// Loop — ทำภารกิจตามแผนที่รู้ล่วงหน้า
// ------------------------------------------------------------
void loop() {
  unsigned long now = millis();
  if (now - prevTime < interval) return;
  prevTime = now;

  currentDist = readDistance();

  switch (task) {
    case 0: // TASK 1: เดินตรง 50 cm ไปเก็บของ
      goStraight(baseYaw);
      if (startDist - currentDist >= 50) { // เดินครบ 50 cm
        stopMotors();
        pickup();
        task++;
        delay(500);
        // เตรียมหมุนขวา
        baseYaw = mpu.getAngleZ();
      }
      break;

    case 1: // TASK 2: หมุนขวา 90°
      {
        float targetYaw = baseYaw + 90;
        mpu.update();
        float currentYaw = mpu.getAngleZ();
        float error = targetYaw - currentYaw;

        if (fabs(error) > 3) drive(-120, 120);
        else {
          stopMotors();
          baseYaw = targetYaw;
          startDist = readDistance();
          task++;
          delay(500);
        }
      }
      break;

    case 2: // TASK 3: เดินตรง 30 cm ไปปล่อยของ
      goStraight(baseYaw);
      if (startDist - currentDist >= 30) {
        stopMotors();
        release();
        task++;
      }
      break;

    default:
      stopMotors();
      break;
  }
}

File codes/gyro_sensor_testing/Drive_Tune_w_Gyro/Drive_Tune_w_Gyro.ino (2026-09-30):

#include <Wire.h>
#include <MPU6050_tockn.h>
#include <Servo.h>

MPU6050 mpu(Wire);

// --- Motor Pins ---
#define MOTOR_B_EN 5
#define MOTOR_B_1 6
#define MOTOR_B_2 7

#define MOTOR_A_EN 10
#define MOTOR_A_1 9
#define MOTOR_A_2 8

// --- Servo Pins ---
Servo myservo1;
Servo myservo2;

// --- Gyro Variables ---
float baseYaw = 0;
float kp = 3.0;   // proportional gain — tune this value for your robot

void setup() {
  Serial.begin(115200);
  Wire.begin();
  mpu.begin();
  mpu.calcGyroOffsets(true);
  Serial.println("MPU6050 calibrated.");

  // Motor setup
  pinMode(MOTOR_A_1, OUTPUT);
  pinMode(MOTOR_A_2, OUTPUT);
  pinMode(MOTOR_A_EN, OUTPUT);

  pinMode(MOTOR_B_1, OUTPUT);
  pinMode(MOTOR_B_2, OUTPUT);
  pinMode(MOTOR_B_EN, OUTPUT);

  // Servo setup
  myservo1.attach(2);
  myservo2.attach(3);

  // Get initial orientation
  delay(1000);
  mpu.update();
  baseYaw = mpu.getAngleZ();
  Serial.println("Base orientation set!");
}

void loop() {
  mpu.update();
  float currentYaw = mpu.getAngleZ();
  float error = currentYaw - baseYaw;

  // Compute correction (simple proportional)
  float correction = kp * error;

  // Base motor speed
  int baseSpeed = 180;

  // Apply correction
  int motorASpeed = constrain(baseSpeed - correction, 100, 255);
  int motorBSpeed = constrain(baseSpeed + correction, 100, 255);

  // Drive forward
  digitalWrite(MOTOR_A_1, LOW);
  digitalWrite(MOTOR_A_2, HIGH);
  analogWrite(MOTOR_A_EN, motorASpeed);

  digitalWrite(MOTOR_B_1, HIGH);
  digitalWrite(MOTOR_B_2, LOW);
  analogWrite(MOTOR_B_EN, motorBSpeed);

  // Print debug
  Serial.print("Yaw: "); Serial.print(currentYaw);
  Serial.print(" | Error: "); Serial.print(error);
  Serial.print(" | A Speed: "); Serial.print(motorASpeed);
  Serial.print(" | B Speed: "); Serial.println(motorBSpeed);

  delay(50);
}
